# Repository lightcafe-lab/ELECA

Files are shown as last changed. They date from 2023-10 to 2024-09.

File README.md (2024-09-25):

# ELECA
ELECA（エレカ）は**CC BY-SA4.0ライセンス**で**名刺デザイン**の**Arduino互換機**です<br>
LIGHTCAFE LAB ELECA 作品ページはこちら<br>
https://lab.lightcafe.co.jp/work/eleca<br>

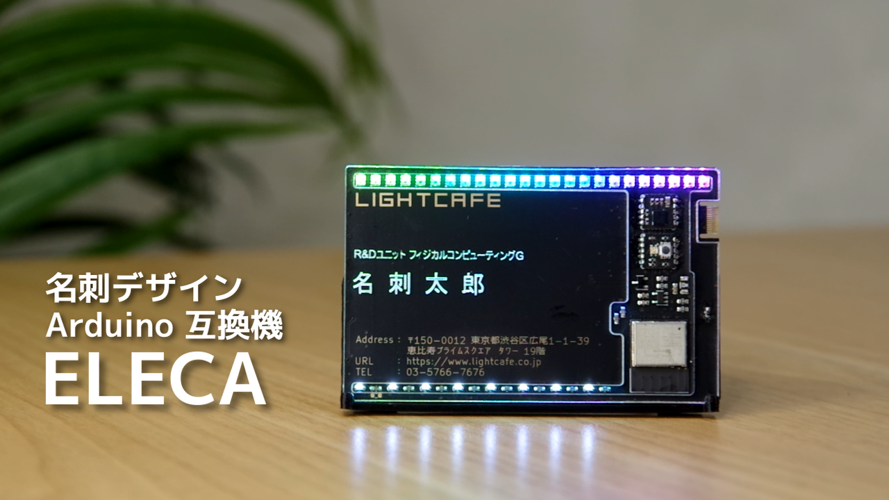
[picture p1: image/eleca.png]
ELECA

## firmware
ELECAに書き込むArduinoのサンプルスケッチです<br>
給電すると動作がはじまります<br>

*eleca-ble-write*<br>
Bluetoothの子機（peripheral）になります<br>

*eleca-hand-pov*<br>
ハンディのバーサライタになります<br>

*eleca-stand*<br>
レインボーが流れていきます<br>

## hardware
ELECA付属のハードウェアです<br>

*3d-print-options*<br>
3DプリントできるELECA専用スタンドです<br>

*acryl-cover*<br>
ELECAの専用アクリルカバーです<br>

## pcb
KiCad (v8.0.3)を使用した回路図と基板図です<br>

*pcb-eleca*<br>
ELECAのメイン基板<br>

*pcb-eleca-extend*<br>
ELECAの拡張スロット用基板<br>
・拡張基板1（加速度センサ）<br>
・拡張基板2（フルカラーLED＋スイッチ）<br>

# ライセンスについて
この 作品 は <a rel="license" href="https://creativecommons.org/licenses/by-sa/4.0/deed.ja">クリエイティブ・コモンズ 表示 - 継承 4.0 国際 ライセンス</a>の下に提供されています<br>
<br />

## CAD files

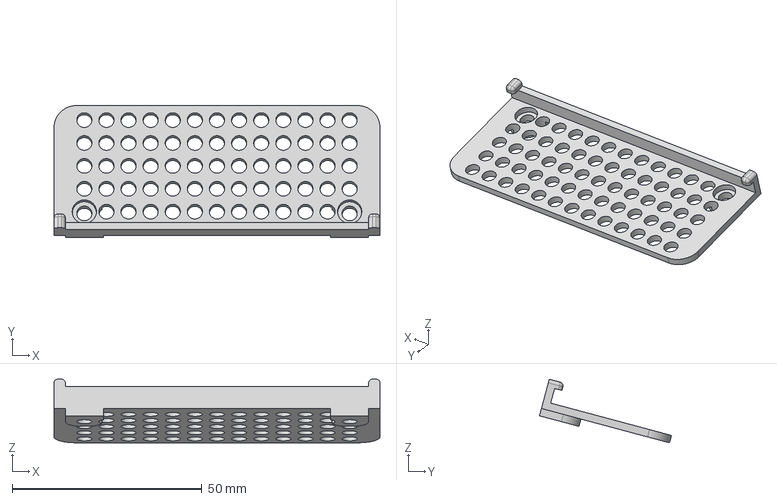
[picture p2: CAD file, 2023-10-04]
hardware/3d-print-options/eleca_card_stand v4.step
86.0 x 34.8 x 16.8 mm

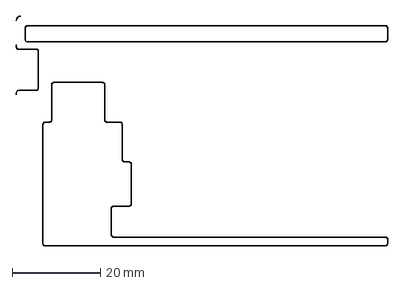
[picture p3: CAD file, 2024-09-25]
hardware/acryl-cover/dxf/eleca-acryl-sculp.dxf
84.0 x 52.0 mm

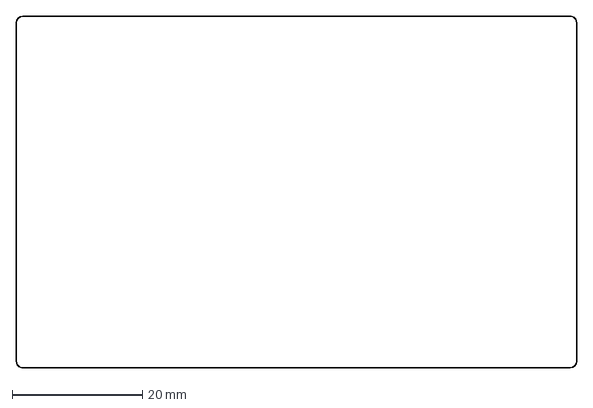
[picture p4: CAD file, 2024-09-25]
hardware/acryl-cover/dxf/eleca-acryl-edge.dxf
86.0 x 54.0 mm

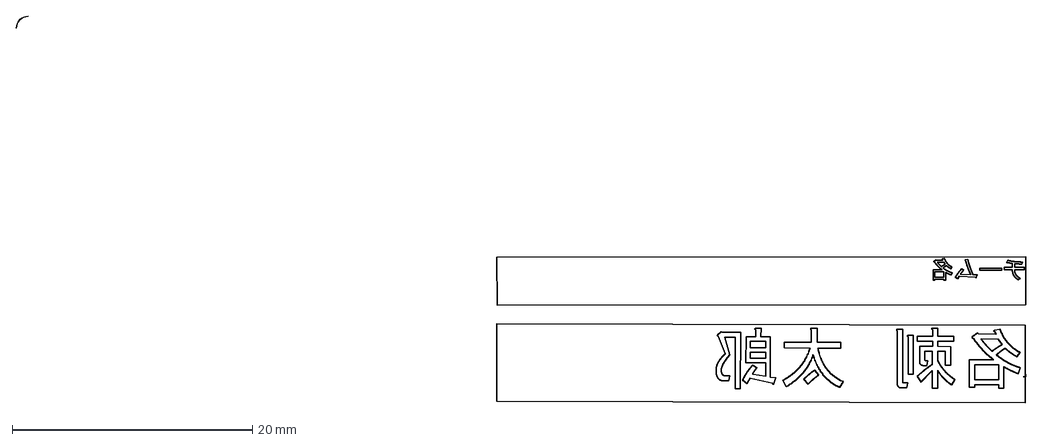
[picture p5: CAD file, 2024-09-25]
hardware/acryl-cover/dxf/eleca-acryl-name.dxf
84.0 x 32.1 mm

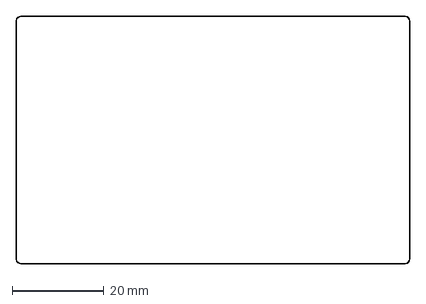
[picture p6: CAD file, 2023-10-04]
hardware/acryl-cover/dxf/eleca-edge-outer.dxf
86.0 x 54.0 mm

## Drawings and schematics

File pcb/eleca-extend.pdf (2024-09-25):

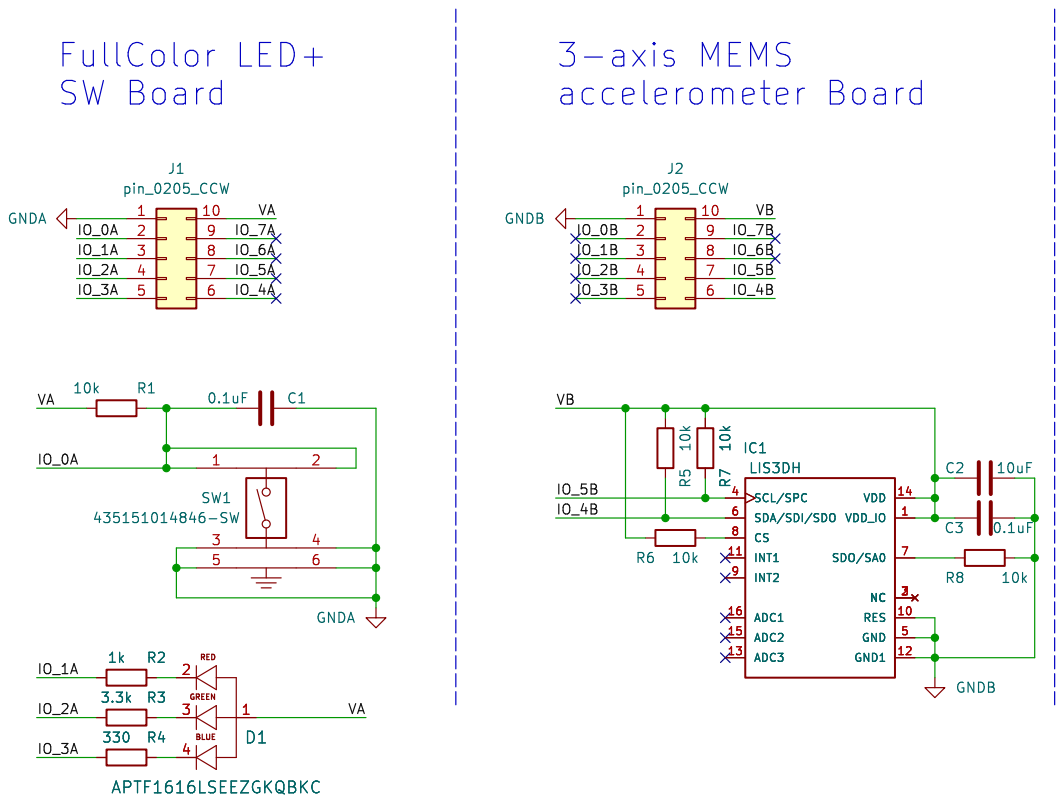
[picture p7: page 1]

Id: 1/1 Title: File: eleca-extend.kicad_sch Sheet: /

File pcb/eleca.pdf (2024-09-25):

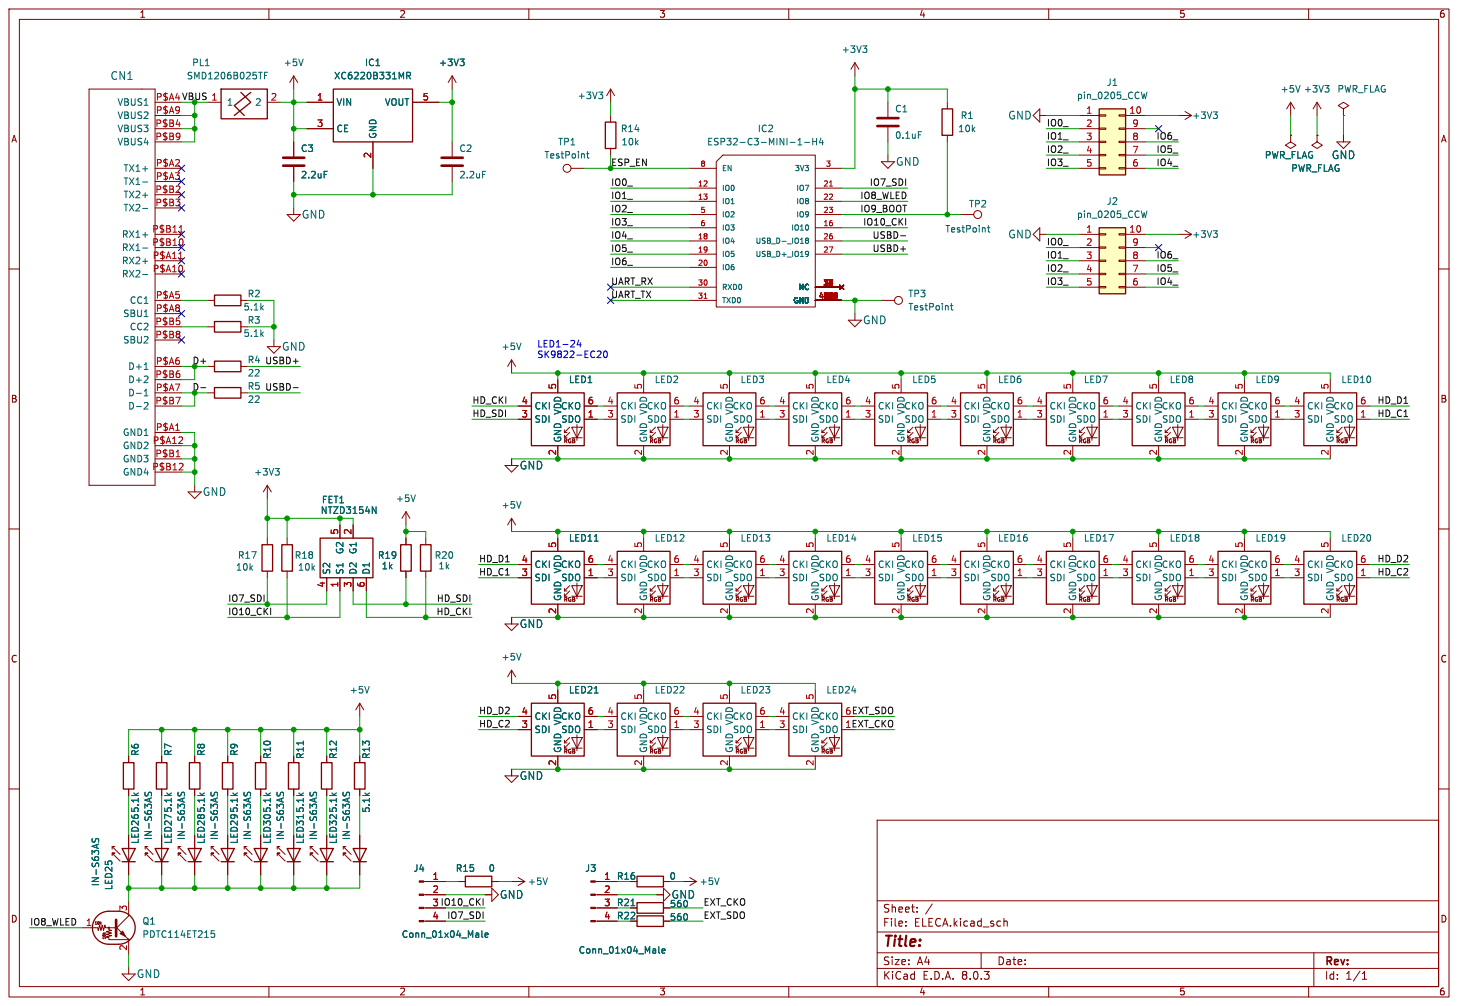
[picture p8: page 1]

2 3 Q1 PDTC114ET215 GND R7 5.1k R6 5.1k LED25 IN-S63AS GND GND

5 CKO 6 R12 5.1k R13 5.1k R11 5.1k LED31 IN-S63AS LED32 IN-S63AS R10 5.1k LED29 IN-S63AS LED30 IN-S63AS GND GND

6 R8 5.1k R9 5.1k LED28 IN-S63AS LED27 IN-S63AS LED26 IN-S63AS R7 5.1k R6 5.1k LED25 IN-S63AS GND

Id: 1/1 Title: File: ELECA.kicad_sch Sheet: /

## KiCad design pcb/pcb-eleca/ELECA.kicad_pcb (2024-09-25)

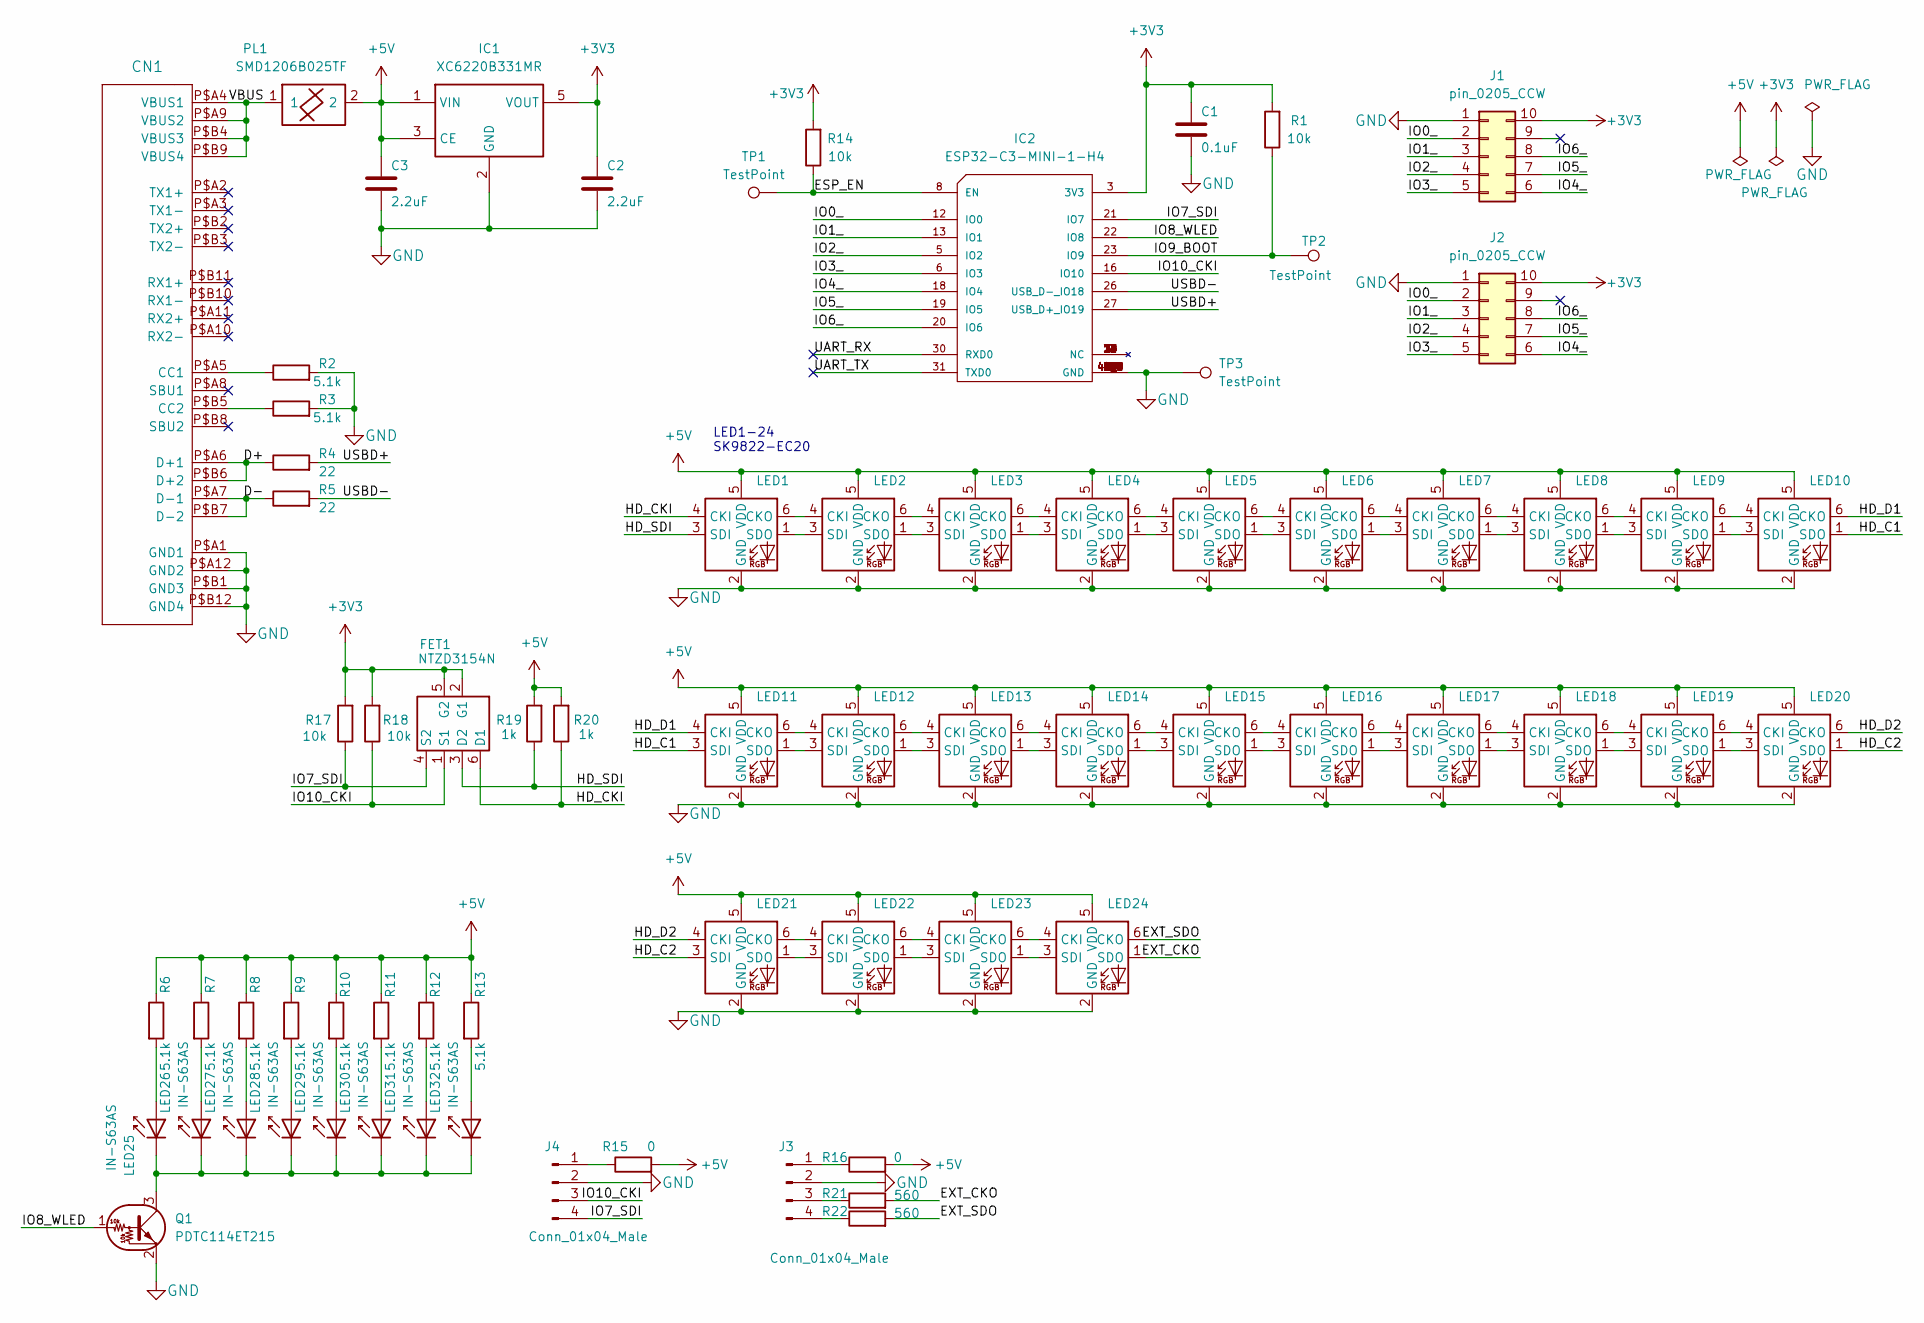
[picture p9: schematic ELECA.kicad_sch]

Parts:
C1: 0.1uF; C_0603_1608Metric
C2, C3: 2.2uF; C_0603_1608Metric
CN1: CON_USB-CPCBPLUG; USB-C_PCBPLUG
FET1: NTZD3154N; NTZD3154NT1G
IC1: XC6220B331MR; SOT-23-5
IC2: ESP32-C3-MINI-1-H4; XCVR_ESP32-C3-MINI-1-N4
J1, J2: pin_0205_CCW; if-8080-10pin-mount-HAT
J3, J4: Conn_01x04_Male; 1×04_pinhead_smd
LED1, LED2, LED3, LED4, LED5, LED6, LED7, LED8, LED9, LED10, LED11, LED12, LED13, LED14, LED15, LED16, LED17, LED18, LED19, LED20, LED21, LED22, LED23, LED24: SK9822-EC20
LED25, LED26, LED27, LED28, LED29, LED30, LED31, LED32: IN-S63AS; IN-S63AS5UW
PL1: SMD1206B025TF; R_1206_3216Metric
Q1: PDTC114ET215; SOT-23-3
R1, R14, R17, R18: 10k; R_0603_1608Metric
R2, R3, R6, R7, R8, R9, R10, R11, R12, R13: 5.1k; R_0603_1608Metric
R4, R5: 22; R_0603_1608Metric
R15, R16: 0; R_0603_1608Metric
R19, R20: 1k; R_0603_1608Metric
R21, R22: 560; R_0603_1608Metric
TP1, TP2, TP3: TestPoint; TestPoint_Pad_D1.5mm

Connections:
+3V3: C1.1, C2.1, FET1.2 (G1), FET1.5 (G2), IC1.5 (VOUT), IC2.3 (3V3), J1.10, J2.10, R1.2, R14.2, R17.2, R18.2
+5V: C3.1, IC1.1 (VIN), IC1.3 (CE), LED1.5 (VDD), LED2.5 (VDD), LED3.5 (VDD), LED4.5 (VDD), LED5.5 (VDD), LED6.5 (VDD), LED7.5 (VDD), LED8.5 (VDD), LED9.5 (VDD), LED10.5 (VDD), LED11.5 (VDD), LED12.5 (VDD), LED13.5 (VDD), LED14.5 (VDD), LED15.5 (VDD), LED16.5 (VDD), LED17.5 (VDD), LED18.5 (VDD), LED19.5 (VDD), LED20.5 (VDD), LED21.5 (VDD), LED22.5 (VDD), LED23.5 (VDD), LED24.5 (VDD), PL1.2, R6.1, R7.1, R8.1, R9.1, R10.1, R11.1, R12.1, R13.1, R15.2, R16.2, R19.2, R20.2
/D+: CN1.P$A6 (D+1), CN1.P$B6 (D+2), R4.1
/D-: CN1.P$A7 (D-1), CN1.P$B7 (D-2), R5.1
/ESP_EN: IC2.8 (EN), R14.1, TP1.1
/EXT_CKO: LED24.1 (SDO), R21.2
/EXT_SDO: LED24.6 (CKO), R22.2
/HD_C1: LED10.1 (SDO), LED11.3 (SDI)
/HD_C2: LED20.1 (SDO), LED21.3 (SDI)
/HD_CKI: FET1.6 (D1), LED1.4 (CKI), R20.1
/HD_D1: LED10.6 (CKO), LED11.4 (CKI)
/HD_D2: LED20.6 (CKO), LED21.4 (CKI)
/HD_SDI: FET1.3 (D2), LED1.3 (SDI), R19.1
/IO0_: IC2.12 (IO0), J1.2, J2.2
/IO1_: IC2.13 (IO1), J1.3, J2.3
/IO2_: IC2.5 (IO2), J1.4, J2.4
/IO3_: IC2.6 (IO3), J1.5, J2.5
/IO4_: IC2.18 (IO4), J1.6, J2.6
/IO5_: IC2.19 (IO5), J1.7, J2.7
/IO6_: IC2.20 (IO6), J1.8, J2.8
/IO7_SDI: FET1.4 (S2), IC2.21 (IO7), J4.4, R17.1
/IO8_WLED: IC2.22 (IO8), Q1.1 (B)
/IO9_BOOT: IC2.23 (IO9), R1.1, TP2.1
/IO10_CKI: FET1.1 (S1), IC2.16 (IO10), J4.3, R18.1
/UART_RX: IC2.30 (RXD0)
/UART_TX: IC2.31 (TXD0)
/USBD+: IC2.27 (USB_D+_IO19), R4.2
/USBD-: IC2.26 (USB_D-_IO18), R5.2
/VBUS: CN1.P$A4 (VBUS1), CN1.P$A9 (VBUS2), CN1.P$B4 (VBUS3), CN1.P$B9 (VBUS4), PL1.1
GND: C1.2, C2.2, C3.2, CN1.P$A1 (GND1), CN1.P$A12 (GND2), CN1.P$B1 (GND3), CN1.P$B12 (GND4), IC1.2 (GND), IC2.1 (GND), IC2.2 (GND), IC2.11 (GND), IC2.14 (GND), IC2.36 (GND), IC2.37 (GND), IC2.38 (GND), IC2.39 (GND), IC2.40 (GND), IC2.41 (GND), IC2.42 (GND), IC2.43 (GND), IC2.44 (GND), IC2.45 (GND), IC2.46 (GND), IC2.47 (GND), IC2.48 (GND), IC2.49_1 (GND), IC2.49_2 (GND), IC2.49_3 (GND), IC2.49_4 (GND), IC2.49_5 (GND), IC2.49_6 (GND), IC2.49_7 (GND), IC2.49_8 (GND), IC2.49_9 (GND), IC2.50 (GND), IC2.51 (GND), IC2.52 (GND), IC2.53 (GND), J1.1, J2.1, J3.2, J4.2, LED1.2 (GND), LED2.2 (GND), LED3.2 (GND), LED4.2 (GND), LED5.2 (GND), LED6.2 (GND), LED7.2 (GND), LED8.2 (GND), LED9.2 (GND), LED10.2 (GND), LED11.2 (GND), LED12.2 (GND), LED13.2 (GND), LED14.2 (GND), LED15.2 (GND), LED16.2 (GND), LED17.2 (GND), LED18.2 (GND), LED19.2 (GND), LED20.2 (GND), LED21.2 (GND), LED22.2 (GND), LED23.2 (GND), LED24.2 (GND), Q1.2 (E), R2.2, R3.2, TP3.1
unnamed: CN1.P$A5 (CC1), R2.1
unnamed: CN1.P$B5 (CC2), R3.1
unnamed: J3.1, R16.1
unnamed: J3.3, R21.1
unnamed: J3.4, R22.1
unnamed: J4.1, R15.1
unnamed: LED1.6 (CKO), LED2.4 (CKI)
unnamed: LED1.1 (SDO), LED2.3 (SDI)
unnamed: LED2.6 (CKO), LED3.4 (CKI)
unnamed: LED2.1 (SDO), LED3.3 (SDI)
unnamed: LED3.6 (CKO), LED4.4 (CKI)
unnamed: LED3.1 (SDO), LED4.3 (SDI)
unnamed: LED4.6 (CKO), LED5.4 (CKI)
unnamed: LED4.1 (SDO), LED5.3 (SDI)
unnamed: LED5.6 (CKO), LED6.4 (CKI)
unnamed: LED5.1 (SDO), LED6.3 (SDI)
unnamed: LED6.6 (CKO), LED7.4 (CKI)
unnamed: LED6.1 (SDO), LED7.3 (SDI)
unnamed: LED7.6 (CKO), LED8.4 (CKI)
unnamed: LED7.1 (SDO), LED8.3 (SDI)
unnamed: LED8.6 (CKO), LED9.4 (CKI)
unnamed: LED8.1 (SDO), LED9.3 (SDI)
unnamed: LED9.6 (CKO), LED10.4 (CKI)
unnamed: LED9.1 (SDO), LED10.3 (SDI)
unnamed: LED11.6 (CKO), LED12.4 (CKI)
unnamed: LED11.1 (SDO), LED12.3 (SDI)
unnamed: LED12.6 (CKO), LED13.4 (CKI)
unnamed: LED12.1 (SDO), LED13.3 (SDI)
unnamed: LED13.6 (CKO), LED14.4 (CKI)
unnamed: LED13.1 (SDO), LED14.3 (SDI)
unnamed: LED14.6 (CKO), LED15.4 (CKI)
unnamed: LED14.1 (SDO), LED15.3 (SDI)
unnamed: LED15.6 (CKO), LED16.4 (CKI)
unnamed: LED15.1 (SDO), LED16.3 (SDI)
unnamed: LED16.6 (CKO), LED17.4 (CKI)
unnamed: LED16.1 (SDO), LED17.3 (SDI)
unnamed: LED17.6 (CKO), LED18.4 (CKI)
unnamed: LED17.1 (SDO), LED18.3 (SDI)
unnamed: LED18.6 (CKO), LED19.4 (CKI)
unnamed: LED18.1 (SDO), LED19.3 (SDI)
unnamed: LED19.6 (CKO), LED20.4 (CKI)
unnamed: LED19.1 (SDO), LED20.3 (SDI)
unnamed: LED21.6 (CKO), LED22.4 (CKI)
unnamed: LED21.1 (SDO), LED22.3 (SDI)
unnamed: LED22.6 (CKO), LED23.4 (CKI)
unnamed: LED22.1 (SDO), LED23.3 (SDI)
unnamed: LED23.6 (CKO), LED24.4 (CKI)
unnamed: LED23.1 (SDO), LED24.3 (SDI)
unnamed: LED25.2 (A), R6.2
unnamed: LED25.1 (K), LED26.1 (K), LED27.1 (K), LED28.1 (K), LED29.1 (K), LED30.1 (K), LED31.1 (K), LED32.1 (K), Q1.3 (C)
unnamed: LED26.2 (A), R7.2
unnamed: LED27.2 (A), R8.2
unnamed: LED28.2 (A), R9.2
unnamed: LED29.2 (A), R10.2
unnamed: LED30.2 (A), R11.2
unnamed: LED31.2 (A), R12.2
unnamed: LED32.2 (A), R13.2

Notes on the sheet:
LED1-24 SK9822-EC20

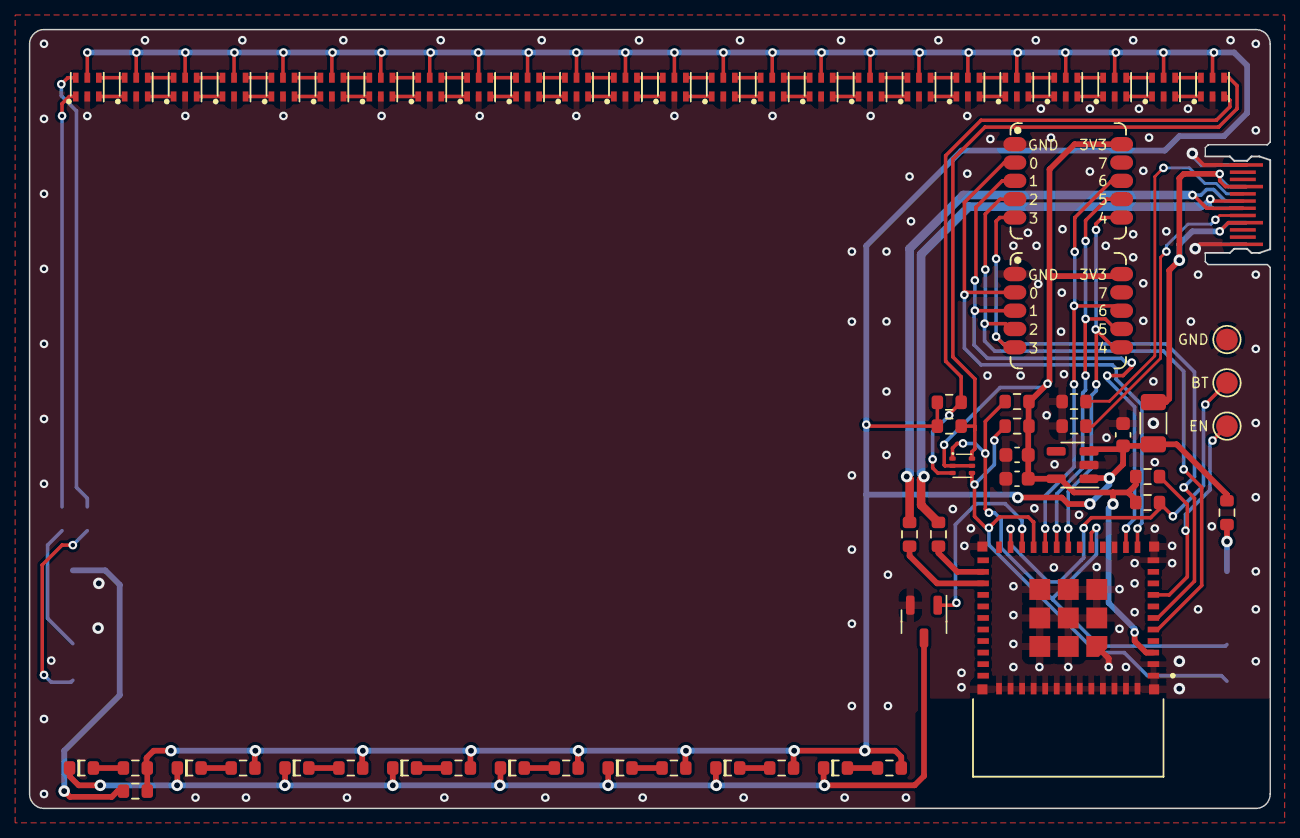
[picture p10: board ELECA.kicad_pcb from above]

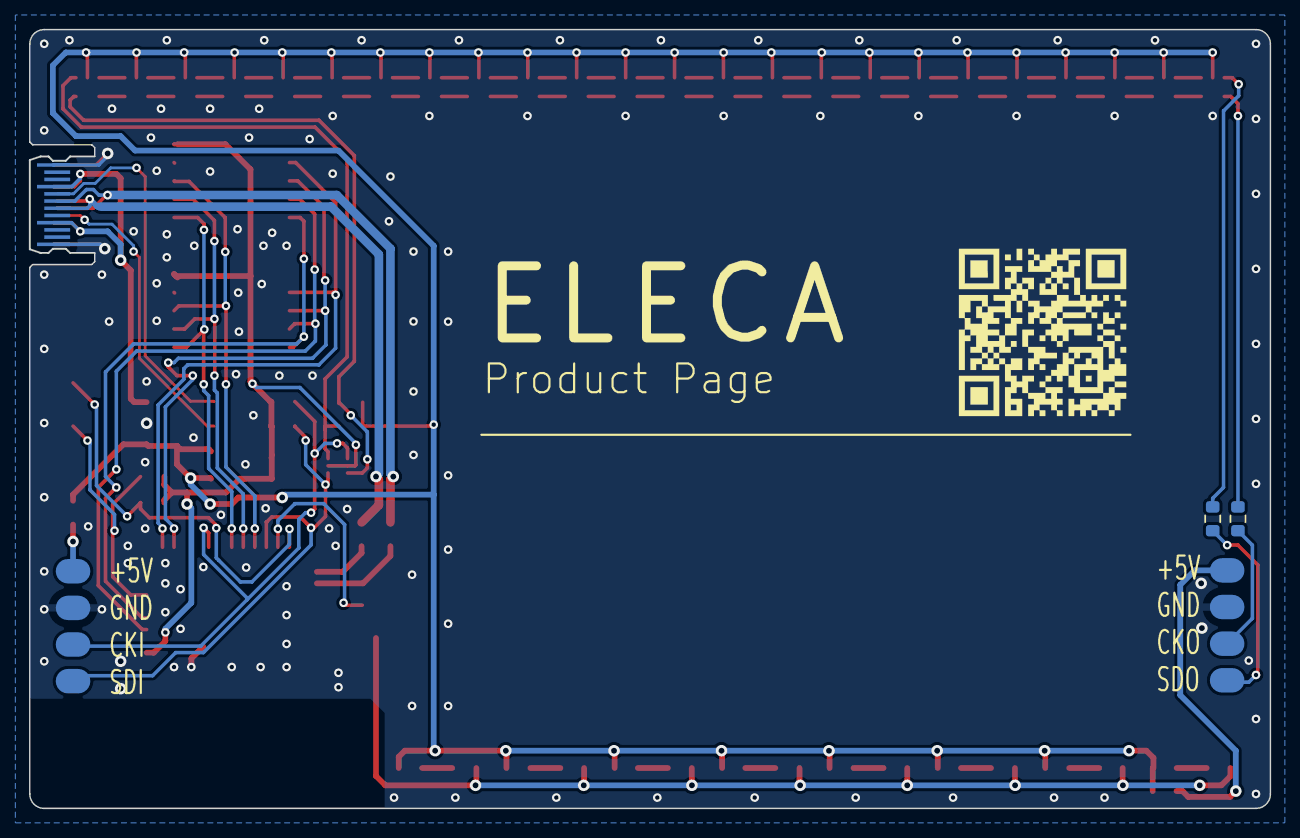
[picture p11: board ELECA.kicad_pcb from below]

Board: 2 copper layers, 86.0 x 54.0 mm, 70 parts (4 on the bottom side), 85 nets.

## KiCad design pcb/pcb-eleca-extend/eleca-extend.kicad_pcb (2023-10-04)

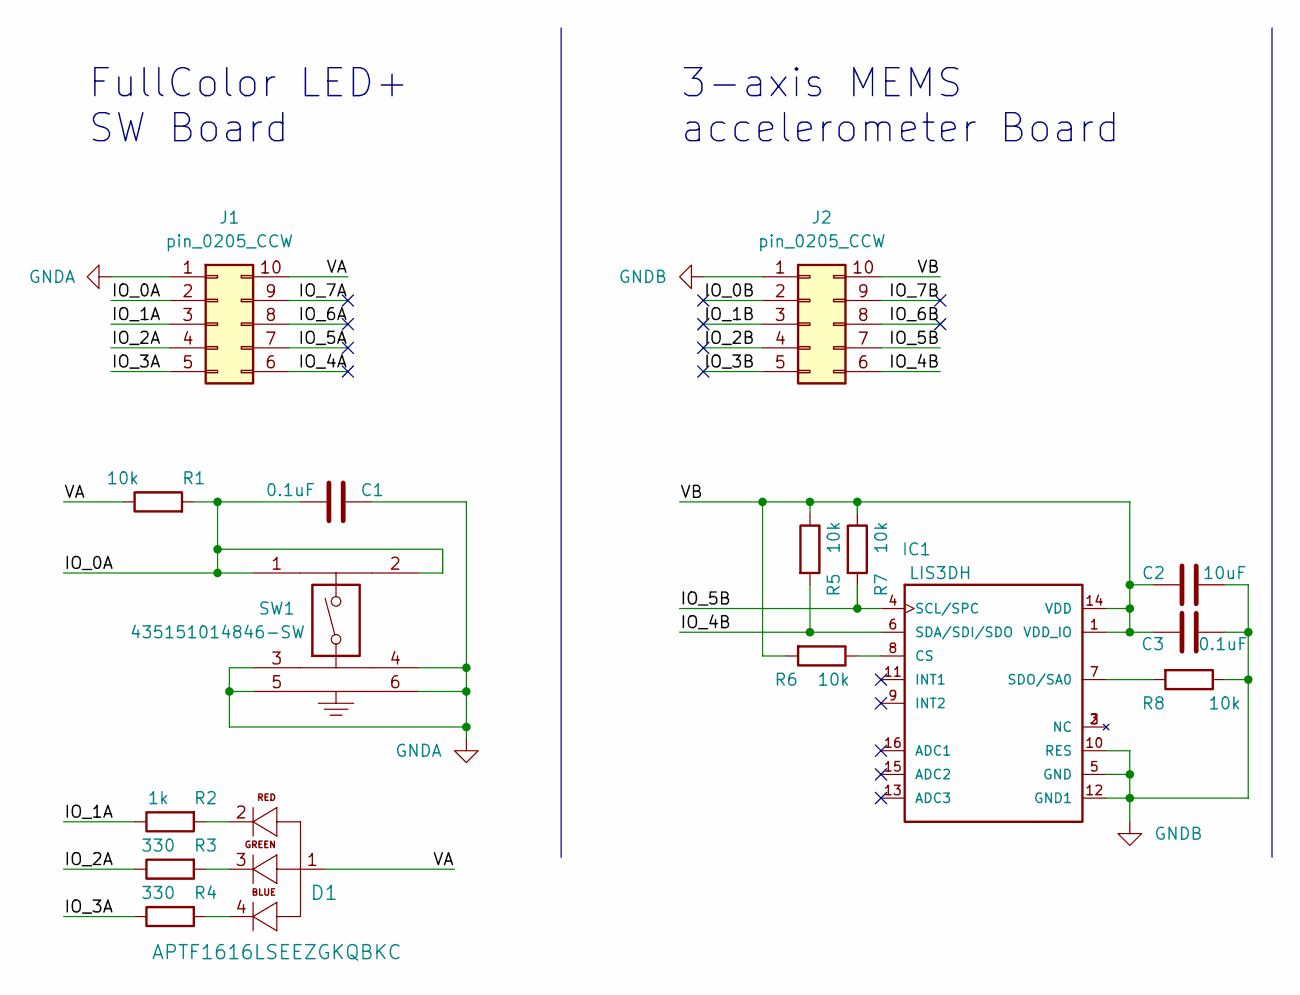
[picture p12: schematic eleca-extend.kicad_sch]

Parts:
C1, C3: 0.1uF; C_0402_1005Metric
C2: 10uF; C_0603_1608Metric
D1: APTF1616LSEEZGKQBKC; LED_APTF1616LSEEZGKQBKC
IC1: LIS3DH
J1, J2: pin_0205_CCW; hachi-8080-10pin-castle
R1, R5, R6, R7, R8: 10k; R_0402_1005Metric
R2: 1k; R_0402_1005Metric
R3, R4: 330; R_0402_1005Metric
SW1: 435151014846-SW; 435151014846

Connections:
/IO_0A: C1.2, J1.2, R1.2, SW1.1, SW1.2
/IO_0B: J2.2
/IO_1A: J1.3, R2.1
/IO_1B: J2.3
/IO_2A: J1.4, R3.1
/IO_2B: J2.4
/IO_3A: J1.5, R4.1
/IO_3B: J2.5
/IO_4A: J1.6
/IO_4B: IC1.6 (SDA/SDI/SDO), J2.6, R5.2
/IO_5A: J1.7
/IO_5B: IC1.4 (SCL/SPC), J2.7, R7.2
/IO_6A: J1.8
/IO_6B: J2.8
/IO_7A: J1.9
/IO_7B: J2.9
/VA: D1.1, J1.10, R1.1
/VB: C2.1, C3.1, IC1.1 (VDD_IO), IC1.14 (VDD), J2.10, R5.1, R6.2, R7.1
GNDA: C1.1, J1.1, SW1.3, SW1.4, SW1.5, SW1.6
GNDB: C2.2, C3.2, IC1.5 (GND), IC1.10 (RES), IC1.12 (GND1), J2.1, R8.1
unnamed: D1.2, R2.2
unnamed: D1.3, R3.2
unnamed: D1.4, R4.2
unnamed: IC1.7 (SDO/SA0), R8.2
unnamed: IC1.8 (CS), R6.1

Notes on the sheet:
3-axis MEMS accelerometer Board
FullColor LED+ SW Board

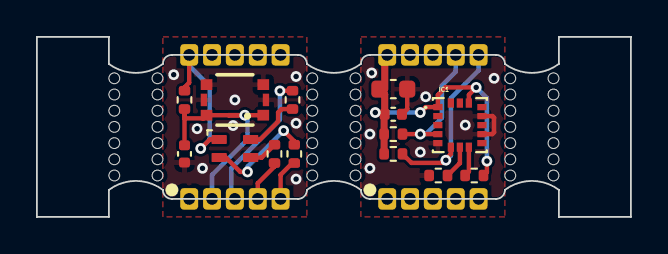
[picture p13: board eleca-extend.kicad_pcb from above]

Board: 2 copper layers, 33.0 x 10.0 mm, 16 parts (0 on the bottom side), 15 nets.

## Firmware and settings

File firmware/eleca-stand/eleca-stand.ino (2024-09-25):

/* This example shows how to make an LED pattern with a large
 * dynamic range using the the extra 5-bit brightness register in
 * the APA102.
 *
 * It sets every LED on the strip to white, zwith the dimmest
 * possible white at the input end of the strip and the brightest
 * possible white at the other end, and a smooth logarithmic
 * gradient between them.
 *
 * The dimmest possible white is achieved by setting the red,
 * green, and blue color channels to 1, and setting the
 * brightness register to 1.  The brightest possibe white is
 * achieved by setting the color channels to 255 and setting the
 * brightness register to 31.
 */

/* By default, the APA102 library uses pinMode and digitalWrite
 * to write to the LEDs, which works on all Arduino-compatible
 * boards but might be slow.  If you have a board supported by
 * the FastGPIO library and want faster LED updates, then install
 * the FastGPIO library and uncomment the next two lines: */
// #include <FastGPIO.h>
// #define APA102_USE_FAST_GPIO

#include <APA102.h>

// Define which pins to use.
const byte dataPin = 7;
const byte clockPin = 10;
const byte interruptPin = 0;
const byte ledR = 1;
const byte ledG = 2;
const byte ledB = 3;
const byte ledW = 8;

// Create an object for writing to the LED strip.
APA102<dataPin, clockPin> ledStrip;

// Set the number of LEDs to control.
const uint16_t ledCount = 48;//24;
// Create a buffer for holding the colors (3 bytes per color).
rgb_color colors[ledCount];
// Set the brightness to use (the maximum is 31).
const uint8_t brightness = 1;

// We define "power" in this sketch to be the product of the
// 8-bit color channel value and the 5-bit brightness register.
// The maximum possible power is 255 * 31 (7905).
const uint16_t maxPower = 255 * 31;

// The power we want to use on the first LED is 1, which
// corresponds to the dimmest possible white.
const uint16_t minPower = 1;

// Calculate what the ratio between the powers of consecutive
// LEDs needs to be in order to reach the max power on the last
// LED of the strip.
const float multiplier = pow(maxPower / minPower, 1.0 / (ledCount - 1));



uint8_t mode=0;
uint8_t fled_mode = 0;
bool ledFlag = 0;

void mode_sw_func() {
  if(ledFlag){
    ledFlag=0;

  mode++;
  if(mode==1){
    fled_mode=0;
    digitalWrite(ledW, HIGH);  
    digitalWrite(ledR, LOW);  
    digitalWrite(ledG, HIGH); 
    digitalWrite(ledB, HIGH); 
  }
  if(mode==2){
    fled_mode=0;
    digitalWrite(ledW, LOW);   
    digitalWrite(ledR, HIGH); 
    digitalWrite(ledG, LOW);  
    digitalWrite(ledB, HIGH); 
  }
  if(mode==3){
    fled_mode=1;    
    digitalWrite(ledW, HIGH);      
    digitalWrite(ledR, HIGH); 
    digitalWrite(ledG, HIGH); 
    digitalWrite(ledB, LOW);  
  }
  if(mode==4){
    fled_mode=1;    
    digitalWrite(ledW, LOW);   
    digitalWrite(ledR, HIGH); 
    digitalWrite(ledG, HIGH); 
    digitalWrite(ledB, HIGH); 
  }
  if(mode==5)mode=0;
    }
}

void setup()
{
  pinMode(ledW, OUTPUT);
  digitalWrite(ledW, HIGH);   // turn the LED on 
//    pinMode(ledR, OUTPUT);
//  digitalWrite(ledR, HIGH);   // turn the LED on 
//    pinMode(ledG, OUTPUT);
//  digitalWrite(ledG, HIGH);   // turn the LED on 
//    pinMode(ledB, OUTPUT);
//  digitalWrite(ledB, HIGH);   // turn the LED on 
//  
//  pinMode(interruptPin, INPUT_PULLUP);
//  attachInterrupt(digitalPinToInterrupt(interruptPin), mode_sw_func, RISING);
}



// This function sends a white color with the specified power,
// which should be between 0 and 7905.
void sendWhite(uint16_t power)
{
  
  // Choose the lowest possible 5-bit brightness that will work.
  uint8_t brightness5Bit = 1;
  while(brightness5Bit * 255 < power && brightness5Bit < 31)
  {
    brightness5Bit++;
  }

  // Uncomment this line to simulate an LED strip that does not
  // have the extra 5-bit brightness register.  You will notice
  // that roughly the first third of the LED strip turns off
  // because the brightness8Bit equals zero.
  //brightness = 31;

  // Set brightness8Bit to be power divided by brightness5Bit,
  // rounded to the nearest whole number.
  uint8_t brightness8Bit = (power + (brightness5Bit / 2)) / brightness5Bit;

  // Send the white color to the LED strip.  At this point,
  // brightness8Bit multiplied by brightness5Bit should be
  // approximately equal to power.
  ledStrip.sendColor(brightness8Bit, brightness8Bit, brightness8Bit, brightness5Bit);
}

/* Converts a color from HSV to RGB.
 * h is hue, as a number between 0 and 360.
 * s is the saturation, as a number between 0 and 255.
 * v is the value, as a number between 0 and 255. */
rgb_color hsvToRgb(uint16_t h, uint8_t s, uint8_t v)
{
    uint8_t f = (h % 60) * 255 / 60;
    uint8_t p = (255 - s) * (uint16_t)v / 255;
    uint8_t q = (255 - f * (uint16_t)s / 255) * (uint16_t)v / 255;
    uint8_t t = (255 - (255 - f) * (uint16_t)s / 255) * (uint16_t)v / 255;
    uint8_t r = 0, g = 0, b = 0;
    switch((h / 60) % 6){
        case 0: r = v; g = t; b = p; break;
        case 1: r = q; g = v; b = p; break;
        case 2: r = p; g = v; b = t; break;
        case 3: r = p; g = q; b = v; break;
        case 4: r = t; g = p; b = v; break;
        case 5: r = v; g = p; b = q; break;
    }
    return rgb_color(r, g, b);
}

void loop()
{

  uint8_t time = millis() >> 5;

  for(uint16_t i = 0; i < ledCount; i++)
  {
    uint8_t p = time - i * 8;
    
  if(fled_mode==0){
    colors[i] = hsvToRgb((uint32_t)p * 359 / 256, 255, 255);  
  }else if(fled_mode==1){
    colors[i] =hsvToRgb(0,0,0);  
  }
  }

  ledStrip.write(colors, ledCount, brightness);

  delay(100);
  ledFlag=1;
}

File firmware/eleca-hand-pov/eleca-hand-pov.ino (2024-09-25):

#include <APA102.h>
#include "Wire.h"
#include "SPI.h"

//pov_handshake_speed
#define CHAR_LC_WIDTH 50
#define CHAR_LC_HEIGHT 16

// Define which pins to use.
const byte dataPin = 7;
const byte clockPin = 10;
const byte interruptPin = 0;
const byte ledW = 8;

// Create an object for writing to the LED strip.
APA102<dataPin, clockPin> ledStrip;

// Set the number of LEDs to control.
const uint16_t ledCount = 24;


// Set the brightness to use (the maximum is 31).
const uint8_t brightness = 2;

// We define "power" in this sketch to be the product of the
// 8-bit color channel value and the 5-bit brightness register.
// The maximum possible power is 255 * 31 (7905).
const uint16_t maxPower = 255 * 31;

// The power we want to use on the first LED is 1, which
// corresponds to the dimmest possible white.
const uint16_t minPower = 1;

// Calculate what the ratio between the powers of consecutive
// LEDs needs to be in order to reach the max power on the last
// LED of the strip.
const float multiplier = pow(maxPower / minPower, 1.0 / (ledCount - 1));

bool pov_init_flag=1;
bool pov_inv_flag=0;
long handShakeSpeedMs=0;
// Create a buffer for holding the colors (3 bytes per color).
rgb_color display_colors[ledCount];
rgb_color preset__cw_colors[ledCount][CHAR_LC_WIDTH];
rgb_color preset_ccw_colors[ledCount][CHAR_LC_WIDTH];

int pov_disp_buf[CHAR_LC_HEIGHT][CHAR_LC_WIDTH]={
  {0,0,2,2,0,3,3,0,4,4,0,5,5,0,6,6,0,7,7,0,8,8,0,0,0,0,0,0,0,0,0,0,0,0},
  {0,0,2,2,0,3,3,0,4,4,0,5,5,0,6,6,0,7,7,0,8,8,0,0,0,0,0,0,0,0,0,0,0,0},
  {0,0,2,2,0,3,3,0,4,4,0,5,5,0,6,6,0,7,7,0,8,8,0,0,0,0,0,0,0,0,0,0,0,0},
  {0,0,0,0,0,0,0,0,0,0,0,0,0,0,0,0,0,0,0,0,0,0,0,0,0,0,0,0,0,0,0,0,0,0},
  {0,0,0,0,0,0,0,0,0,0,0,0,0,0,0,0,0,0,0,0,0,0,0,0,0,0,0,0,0,0,0,0,0,0},
  {0,0,0,0,0,0,0,0,0,0,0,0,0,0,0,0,0,0,0,0,0,0,0,0,0,0,0,0,0,0,0,0,0,0},
  {0,0,0,0,0,0,0,0,0,0,0,0,0,0,0,0,0,0,0,0,0,0,0,0,0,0,0,0,0,0,0,0,0,0},
  {0,0,1,0,0,0,1,0,1,1,1,1,0,1,0,1,0,1,1,1,0,1,1,0,0,1,0,0,1,1,0,1,1,0},
  {0,0,1,0,0,0,1,0,1,0,0,0,0,1,0,1,0,0,1,0,0,1,0,0,1,0,1,0,1,0,0,1,0,0},
  {0,0,1,0,0,0,1,0,1,0,0,0,0,1,0,1,0,0,1,0,0,1,0,0,1,0,1,0,1,0,0,1,0,0},
  {0,0,1,0,0,0,1,0,1,0,1,1,0,1,1,1,0,0,1,0,0,1,0,0,1,0,1,0,1,1,0,1,1,0},
  {0,0,1,0,0,0,1,0,1,0,0,1,0,1,0,1,0,0,1,0,0,1,0,0,1,1,1,0,1,0,0,1,0,0},
  {0,0,1,0,0,0,1,0,1,0,0,1,0,1,0,1,0,0,1,0,0,1,0,0,1,0,1,0,1,0,0,1,0,0},
  {0,0,1,1,1,0,1,0,1,1,1,1,0,1,0,1,0,0,1,0,0,1,1,0,1,0,1,0,1,0,0,1,1,0},
  {0,0,0,0,0,0,0,0,0,0,0,0,0,0,0,0,0,0,0,0,0,0,0,0,0,0,0,0,0,0,0,0,0,0},
  {0,0,0,0,0,0,0,0,0,0,0,0,0,0,0,0,0,0,0,0,0,0,0,0,0,0,0,0,0,0,0,0,0,0}
};
uint16_t hsv_b[9][3]={
   {0,0,0},  {240,255,255},  { 60,255,255}, //none,char,yellow
   {  0,255,255},  {300,255,255},  {190,255,255}, //red,purple,skyblue
   {240,255,255},  { 70,255,255},  {120,255,255}  //blue,palegreen,green
};

void pov_setup(){
  for (int j=0; j < CHAR_LC_WIDTH-1; j++) {
      for (int k=0; k<CHAR_LC_HEIGHT-1;k++){
      
        preset__cw_colors[ledCount-k-1][j]=hsvToRgb( 
                                          hsv_b[pov_disp_buf[k][j]][0],
                                          hsv_b[pov_disp_buf[k][j]][1],
                                          hsv_b[pov_disp_buf[k][j]][2]);
        preset_ccw_colors[ledCount-k-1][j]=hsvToRgb( 
                                          hsv_b[pov_disp_buf[k][CHAR_LC_WIDTH-1-j]][0],
                                          hsv_b[pov_disp_buf[k][CHAR_LC_WIDTH-1-j]][1],
                                          hsv_b[pov_disp_buf[k][CHAR_LC_WIDTH-1-j]][2]);        
                                        
//    Serial.print(preset__cw_colors[k][j][1],3);
//    Serial.print(preset__cw_colors[k][j][2],3);
    }
  }
}
void pov_run(){
  pov_inv_flag=!pov_inv_flag;
  for (int j=0; j < (CHAR_LC_WIDTH-1); j++) {
      for (int k=0; k<ledCount;k++){
        if(pov_inv_flag){
          display_colors[k] = preset__cw_colors[k][j];
          //digitalWrite(ledW, LOW);   // turn the LED on
        }
        else if(!pov_inv_flag){
          display_colors[k] = preset_ccw_colors[k][j];
          //digitalWrite(ledW, HIGH);   // turn the LED on
        }
        
       //   display_colors[k] = preset__cw_colors[k][j];
      //display_colors[k] = preset_ccw_colors[k][j];

    }
  
    ledStrip.write(display_colors, ledCount, brightness);
    delay(3); 
  }
}
/* Converts a color from HSV to RGB.
 * h is hue, as a number between 0 and 360.
 * s is the saturation, as a number between 0 and 255.
 * v is the value, as a number between 0 and 255. */
rgb_color hsvToRgb(uint16_t h, uint8_t s, uint8_t v)
{
    uint8_t f = (h % 60) * 255 / 60;
    uint8_t p = (255 - s) * (uint16_t)v / 255;
    uint8_t q = (255 - f * (uint16_t)s / 255) * (uint16_t)v / 255;
    uint8_t t = (255 - (255 - f) * (uint16_t)s / 255) * (uint16_t)v / 255;
    uint8_t r = 0, g = 0, b = 0;
    switch((h / 60) % 6){
        case 0: r = v; g = t; b = p; break;
        case 1: r = q; g = v; b = p; break;
        case 2: r = p; g = v; b = t; break;
        case 3: r = p; g = q; b = v; break;
        case 4: r = t; g = p; b = v; break;
        case 5: r = v; g = p; b = q; break;
    }
    return rgb_color(r, g, b);
}

void setup() {
  pinMode(ledW, OUTPUT);
  digitalWrite(ledW, LOW);   // turn the LED on
  // put your setup code here, to run once:
  Serial.begin(9600);
  delay(1000); 

  //relax...
  uint8_t time = millis() >> 5;
  for(uint16_t i = 0; i < ledCount; i++)
  {
    uint8_t p = time - i * 8;
    display_colors[i] = hsvToRgb(0,0,0);
  }

  ledStrip.write(display_colors, ledCount, brightness);
  
  pov_setup();
}


void loop()
{
  pov_run();
  delay(40); 
}
